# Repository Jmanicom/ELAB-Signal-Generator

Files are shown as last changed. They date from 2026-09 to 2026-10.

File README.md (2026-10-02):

# ELAB-Signal-Generator
A square wave generator with adjustable frequency, gain, and offset control. Designed as a part of UBC's ELAB PCB design course.

### **Skills used in this project**
***KiCad, Analog Circuit Design, Hand Soldering, Testing/Validation***

---

<p float="left">
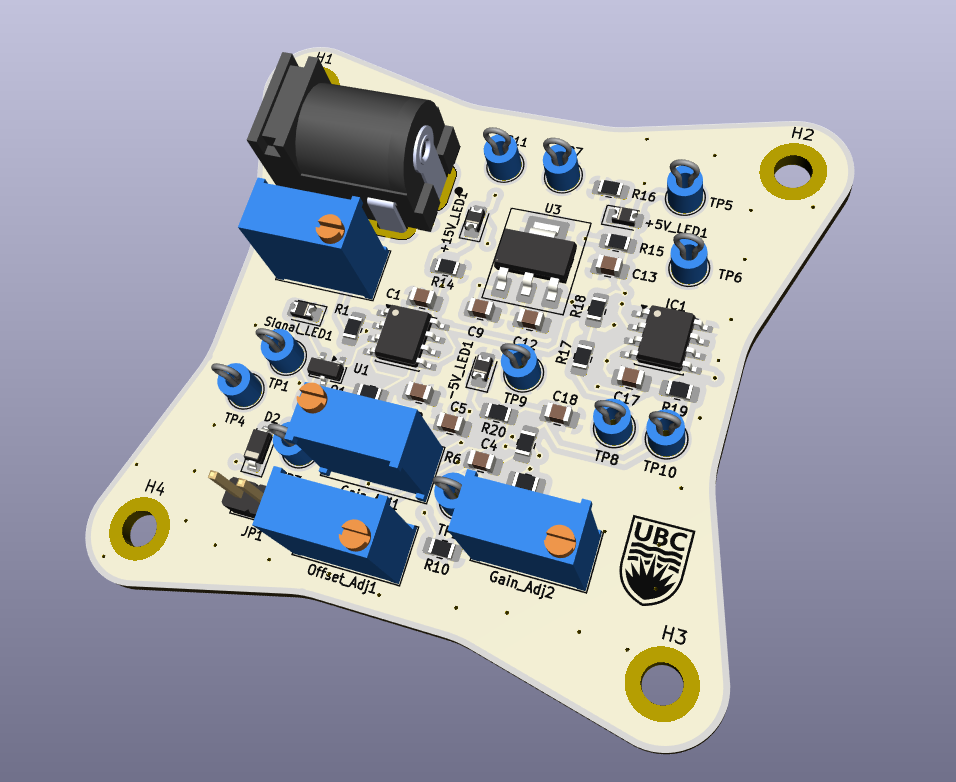
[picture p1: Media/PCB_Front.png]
  
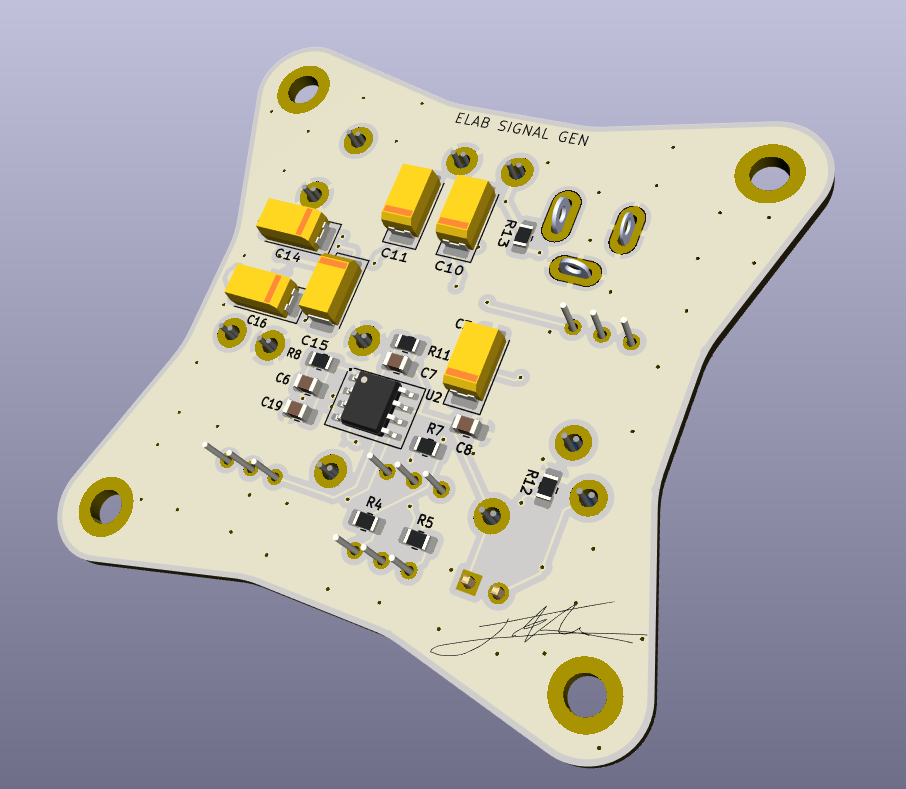
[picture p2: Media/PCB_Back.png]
  
</p>

# Design
The design for this signal generator is not complex, this is because it's main purpose was to provide an opportunity to design 
and assemble a PCB from the start to finish of the production cycle. This included schematic capture, component/footprint library 
creation, component layout, laying traces, and laying polygon pours. In the second stage of the course, we received our boards and 
components and assembled them using hand soldering, and tested them using an oscilloscope to view our signals and test the various 
adjustments.

## Power Supply
The signal generator utilizes +/-5V rails to be able produce a maximum of a 10V peak-to-peak
signal. 15V  comes from a barrel jack connections from a wall adapter, which is then 
regulated using the **LM7805** to drop to it to +5V. This rail then feeds into the **MAX889** that
produces the complimentary -5V rail. Output capacitors are used to help with input noise, and output voltage ripple.

<p>
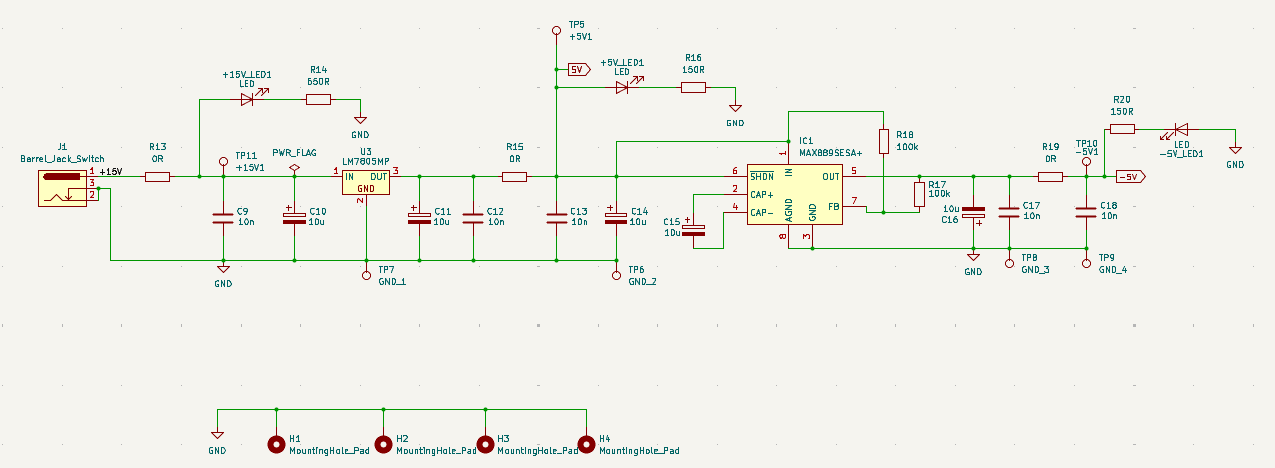
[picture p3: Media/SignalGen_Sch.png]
  
</p>

## Signal Amplifier
The square wave signal is generated by the **NE555**, that includes a frequency adjust potentiometer. This signal is then fed to 
the **AD8039** with two amplifier stages to control gain and offset respectively. Additional bypass capacitors are placed
on the op-amps power rails to help with further noise reduction and to help stabilize voltage. Finally, a 3.3V peak-limiter zener
diode is placed on the output which can be engaged with the use of a jumper. 

<p>
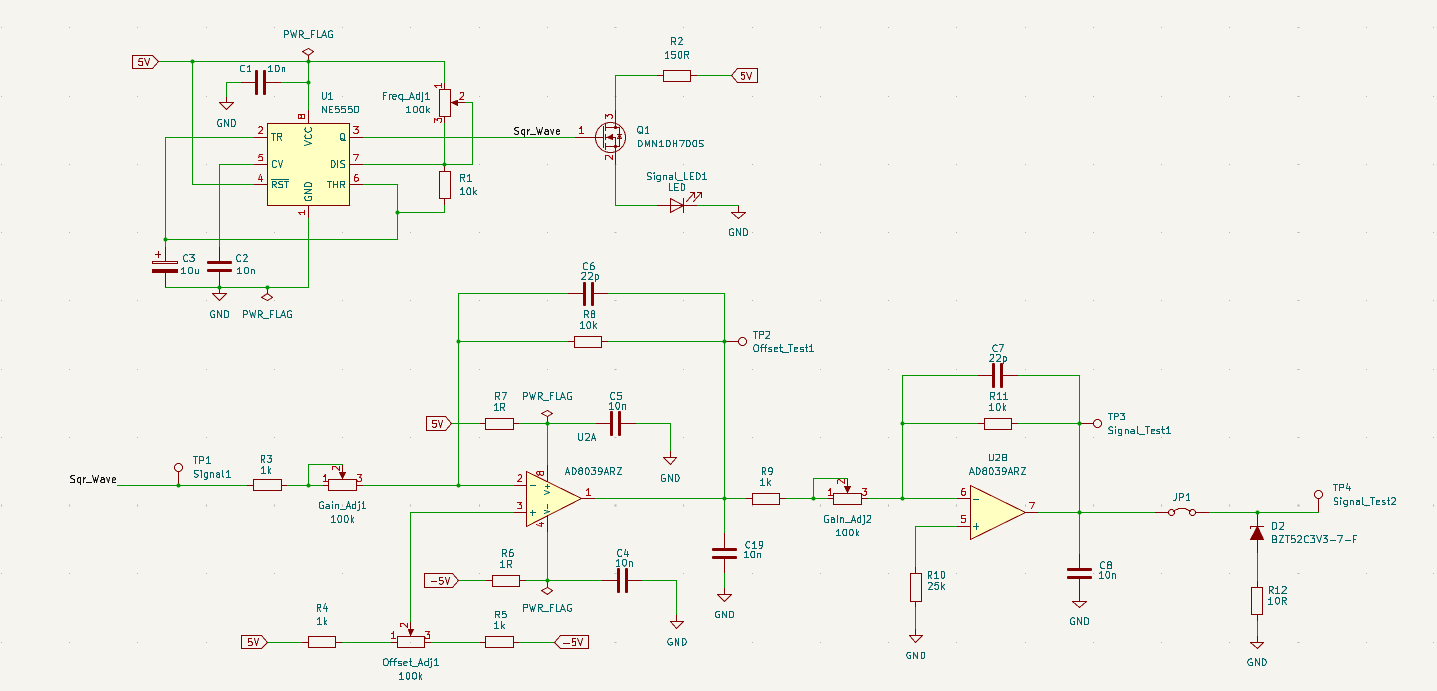
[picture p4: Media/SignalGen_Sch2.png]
  
</p>

## PCB Design
With this being my first attempt at PCB design, there is room for improvement with my traces decisions component placement.
With this project, we were constrained on the size of board that we could use, additionally, I wanted to make a unique shape
for my board that tends to be a popular shape for small desings that need to be mounted.

The large 1206 capacitors were placed on the back side of the board as they are quite bulky and left very little room for other
components on the board. This board features 2-layers with ground pours on each layer, as well as stitching vias to help further
with noise.

<p float="left">
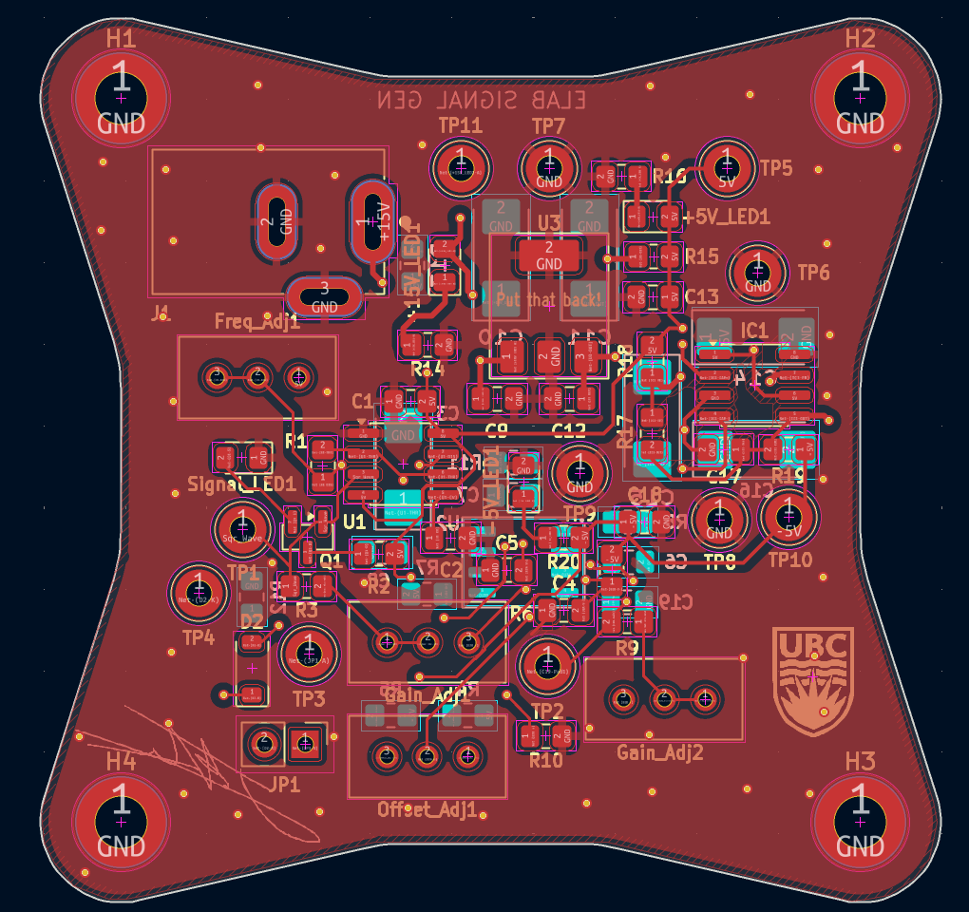
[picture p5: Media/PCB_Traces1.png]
  
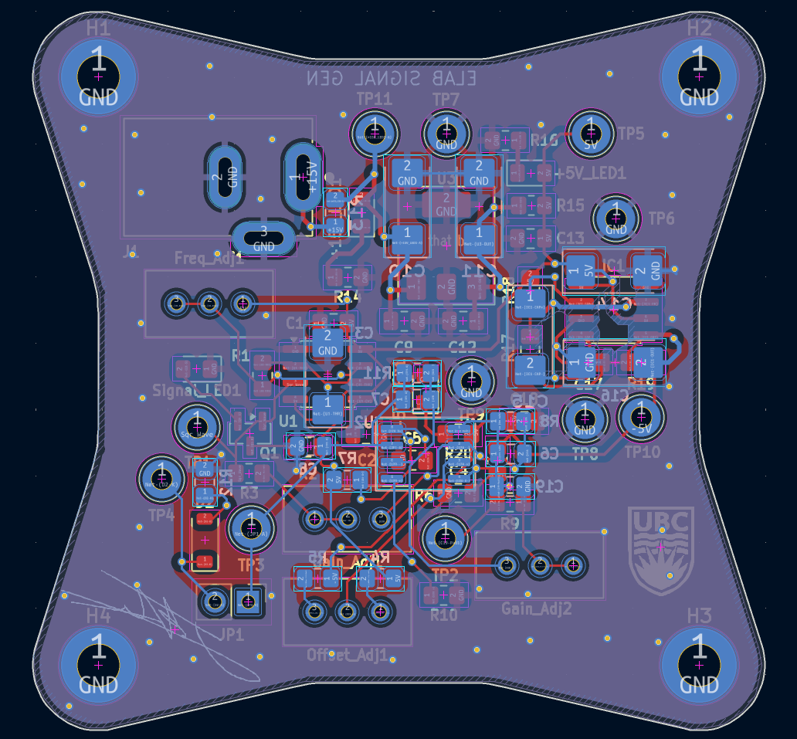
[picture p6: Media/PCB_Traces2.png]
  
</p>

# Assembly

# Testing

# Notes

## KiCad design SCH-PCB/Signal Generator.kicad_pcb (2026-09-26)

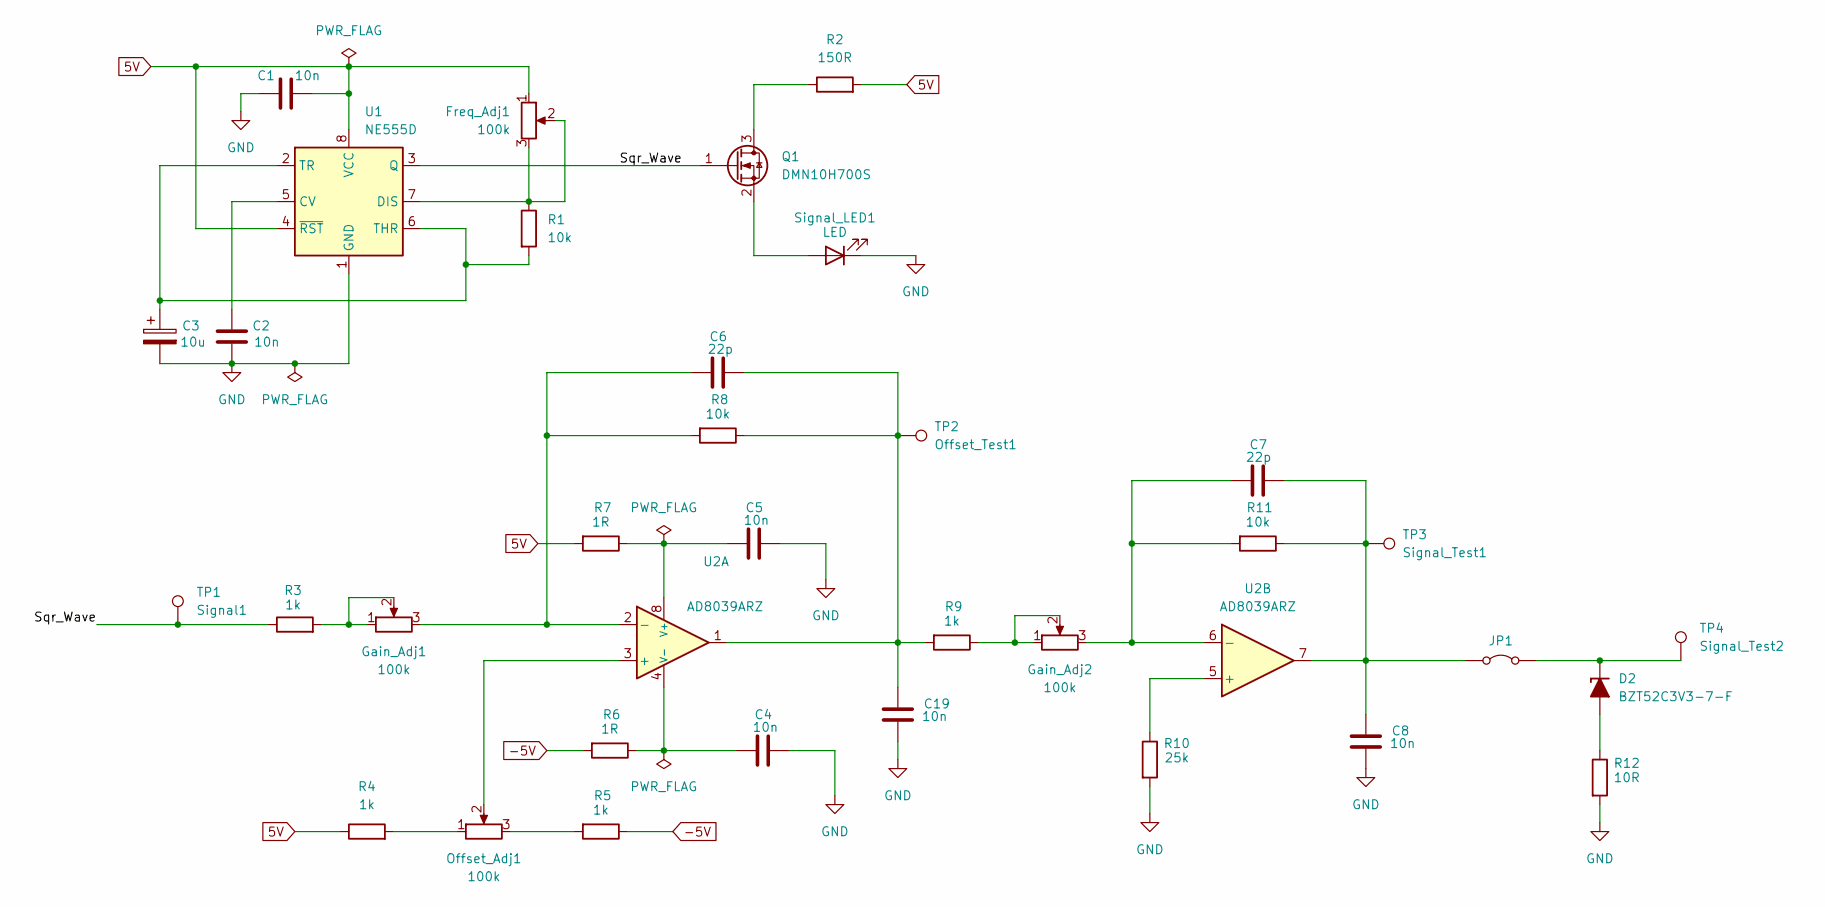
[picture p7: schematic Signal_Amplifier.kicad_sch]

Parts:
C1, C2, C4, C5, C8, C19: 10n; C_0805_2012Metric_Pad1.18x1.45mm_HandSolder
C3: 10u; CP_EIA-6032-28_Kemet-C_HandSolder
C6, C7: 22p; C_0805_2012Metric_Pad1.18x1.45mm_HandSolder
D2: BZT52C3V3-7-F; D_SOD-123
Freq_Adj1: 100k; Potentiometer_Bourns_3296W_Vertical
Gain_Adj1, Gain_Adj2: 100k; Potentiometer_Bourns_3296W_Vertical
JP1: Jumper_2_Bridged; PinHeader_1x02_P2.54mm_Vertical
Offset_Adj1: 100k; Potentiometer_Bourns_3296W_Vertical
Q1: DMN10H700S; SOT-23
R1, R8, R11: 10k; R_0805_2012Metric_Pad1.20x1.40mm_HandSolder
R2: 150R; R_0805_2012Metric_Pad1.20x1.40mm_HandSolder
R3, R4, R5, R9: 1k; R_0805_2012Metric_Pad1.20x1.40mm_HandSolder
R6, R7: 1R; R_0805_2012Metric_Pad1.20x1.40mm_HandSolder
R10: 25k; R_0805_2012Metric_Pad1.20x1.40mm_HandSolder
R12: 10R; R_0805_2012Metric_Pad1.20x1.40mm_HandSolder
Signal_LED1: LED; D_0805_2012Metric_Pad1.15x1.40mm_HandSolder
TP1: Signal1; TestPoint_Loop_D2.54mm_Drill1.5mm_Beaded
TP2: Offset_Test1; TestPoint_Loop_D2.54mm_Drill1.5mm_Beaded
TP3: Signal_Test1; TestPoint_Loop_D2.54mm_Drill1.5mm_Beaded
TP4: Signal_Test2; TestPoint_Loop_D2.54mm_Drill1.5mm_Beaded
U1: NE555D; SOIC-8_3.9x4.9mm_P1.27mm
U2: AD8039ARZ; SO-8_3.9x4.9mm_P1.27mm

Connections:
5V: C1.2, Freq_Adj1.1, R2.2, R4.1, R7.2, U1.4 (~RST), U1.8 (VCC); also elsewhere on the board
-5V: R5.1, R6.2; also elsewhere on the board
/Signal_Amplifier/Sqr_Wave: Q1.1 (G), R3.1, TP1.1 (1_1), U1.3 (Q)
GND: C1.1, C2.2, C3.2, C4.1, C5.1, C8.2, C19.2, R10.2, R12.2, Signal_LED1.1 (K), U1.1 (GND); also elsewhere on the board
unnamed: C6.1, C19.1, R8.1, R9.2, TP2.1 (1_1), U2.1
unnamed: D2.2 (A), R12.1
unnamed: D2.1 (K), JP1.2 (B), TP4.1 (1_1)
unnamed: Gain_Adj1.1, Gain_Adj1.2, R3.2
unnamed: Gain_Adj2.1, Gain_Adj2.2, R9.1
unnamed: C7.1, C8.1, JP1.1 (A), R11.1, TP3.1 (1_1), U2.7
unnamed: Offset_Adj1.1, R4.2
unnamed: Offset_Adj1.3, R5.2
unnamed: Q1.3 (D), R2.1
unnamed: Q1.2 (S), Signal_LED1.2 (A)
unnamed: C2.1, U1.5 (CV)
unnamed: Freq_Adj1.2, Freq_Adj1.3, R1.1, U1.7 (DIS)
unnamed: C3.1, R1.2, U1.2 (TR), U1.6 (THR)
unnamed: Offset_Adj1.2, U2.3 (+)
unnamed: C6.2, Gain_Adj1.3, R8.2, U2.2 (-)
unnamed: C5.2, R7.1, U2.8 (V+)
unnamed: C4.2, R6.1, U2.4 (V-)
unnamed: R10.1, U2.5 (+)
unnamed: C7.2, Gain_Adj2.3, R11.2, U2.6 (-)

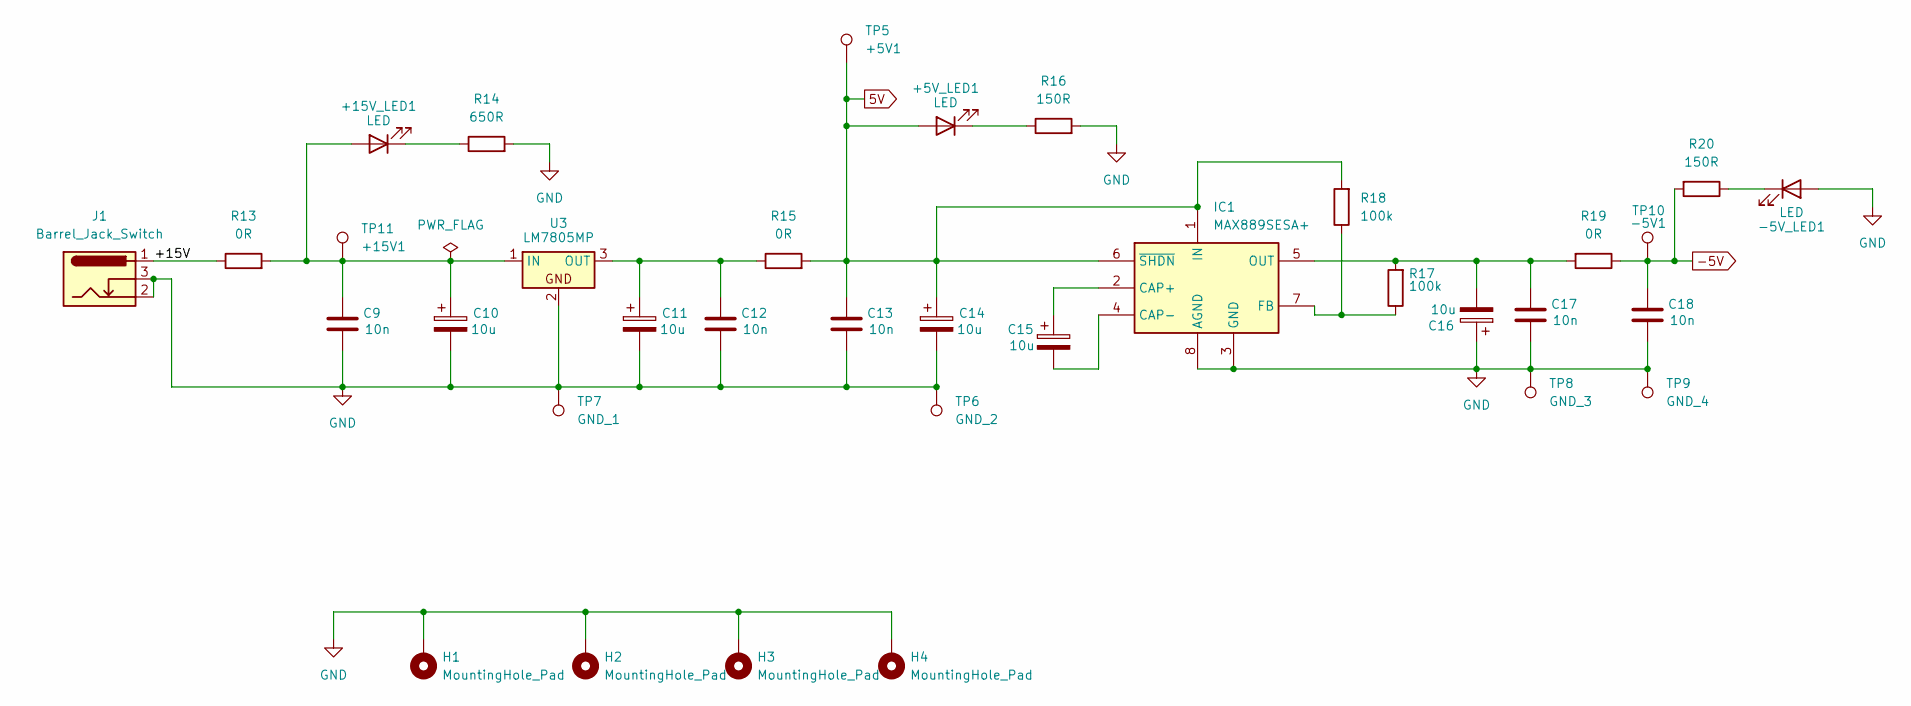
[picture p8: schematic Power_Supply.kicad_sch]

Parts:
+5V_LED1, +15V_LED1: LED; D_0805_2012Metric_Pad1.15x1.40mm_HandSolder
-5V_LED1: LED; D_0805_2012Metric_Pad1.15x1.40mm_HandSolder
C9, C12, C13, C17, C18: 10n; C_0805_2012Metric_Pad1.18x1.45mm_HandSolder
C10, C11, C14, C15, C16: 10u; CP_EIA-6032-28_Kemet-C_HandSolder
H1, H2, H3, H4: MountingHole_Pad; MountingHole_3.2mm_M3_DIN965_Pad
IC1: MAX889SESA+; SOIC-8_3.9x4.9mm_P1.27mm; Manufacturer_Part_Number MAX889SESA+; Mouser Part Number 700-MAX889SESA
J1: Barrel_Jack_Switch; CUI_PJ-002A
R13, R15, R19: 0R; R_0805_2012Metric_Pad1.20x1.40mm_HandSolder
R14: 650R; R_0805_2012Metric_Pad1.20x1.40mm_HandSolder
R16, R20: 150R; R_0805_2012Metric_Pad1.20x1.40mm_HandSolder
R17, R18: 100k; R_0805_2012Metric_Pad1.20x1.40mm_HandSolder
TP5: +5V1; TestPoint_Loop_D2.54mm_Drill1.5mm_Beaded
TP6: GND_2; TestPoint_Loop_D2.54mm_Drill1.5mm_Beaded
TP7: GND_1; TestPoint_Loop_D2.54mm_Drill1.5mm_Beaded
TP8: GND_3; TestPoint_Loop_D2.54mm_Drill1.5mm_Beaded
TP9: GND_4; TestPoint_Loop_D2.54mm_Drill1.5mm_Beaded
TP10: -5V1; TestPoint_Loop_D2.54mm_Drill1.5mm_Beaded
TP11: +15V1; TestPoint_Loop_D2.54mm_Drill1.5mm_Beaded
U3: LM7805MP; SOT-223-3_TabPin2

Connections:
5V: +5V_LED1.2 (A), C13.1, C14.1, IC1.1 (IN), IC1.6 (~SHDN), R15.2, R18.2, TP5.1 (1_1); also elsewhere on the board
-5V: C18.1, R19.1, R20.2, TP10.1 (1_1); also elsewhere on the board
/Power_Supply/+15V: J1.1, R13.1
GND: -5V_LED1.2 (A), C9.2, C10.2, C11.2, C12.2, C13.2, C14.2, C16.1, C17.2, C18.2, H1.1 (1_1), H2.1 (1_1), H3.1 (1_1), H4.1 (1_1), IC1.3 (GND), IC1.8 (AGND), J1.2, J1.3, R14.2, R16.2, TP6.1 (1_1), TP7.1 (1_1), TP8.1 (1_1), TP9.1 (1_1), U3.2; also elsewhere on the board
unnamed: +5V_LED1.1 (K), R16.1
unnamed: +15V_LED1.2 (A), C9.1, C10.1, R13.2, TP11.1 (1_1), U3.1 (IN)
unnamed: +15V_LED1.1 (K), R14.1
unnamed: -5V_LED1.1 (K), R20.1
unnamed: C15.1, IC1.2 (CAP+)
unnamed: C15.2, IC1.4 (CAP-)
unnamed: IC1.7 (FB), R17.1, R18.1
unnamed: C16.2, C17.1, IC1.5 (OUT), R17.2, R19.2
unnamed: C11.1, C12.1, R15.1, U3.3 (OUT)

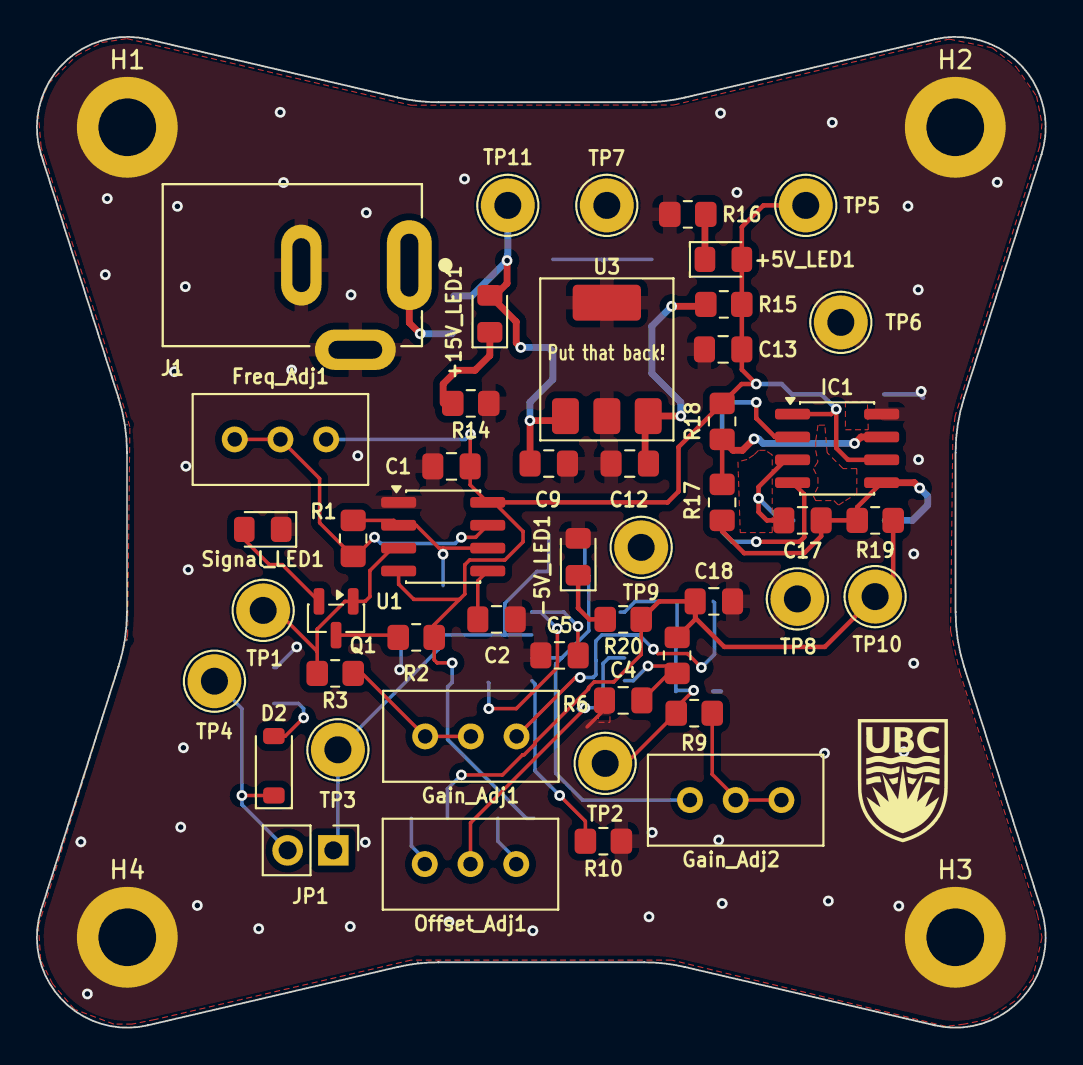
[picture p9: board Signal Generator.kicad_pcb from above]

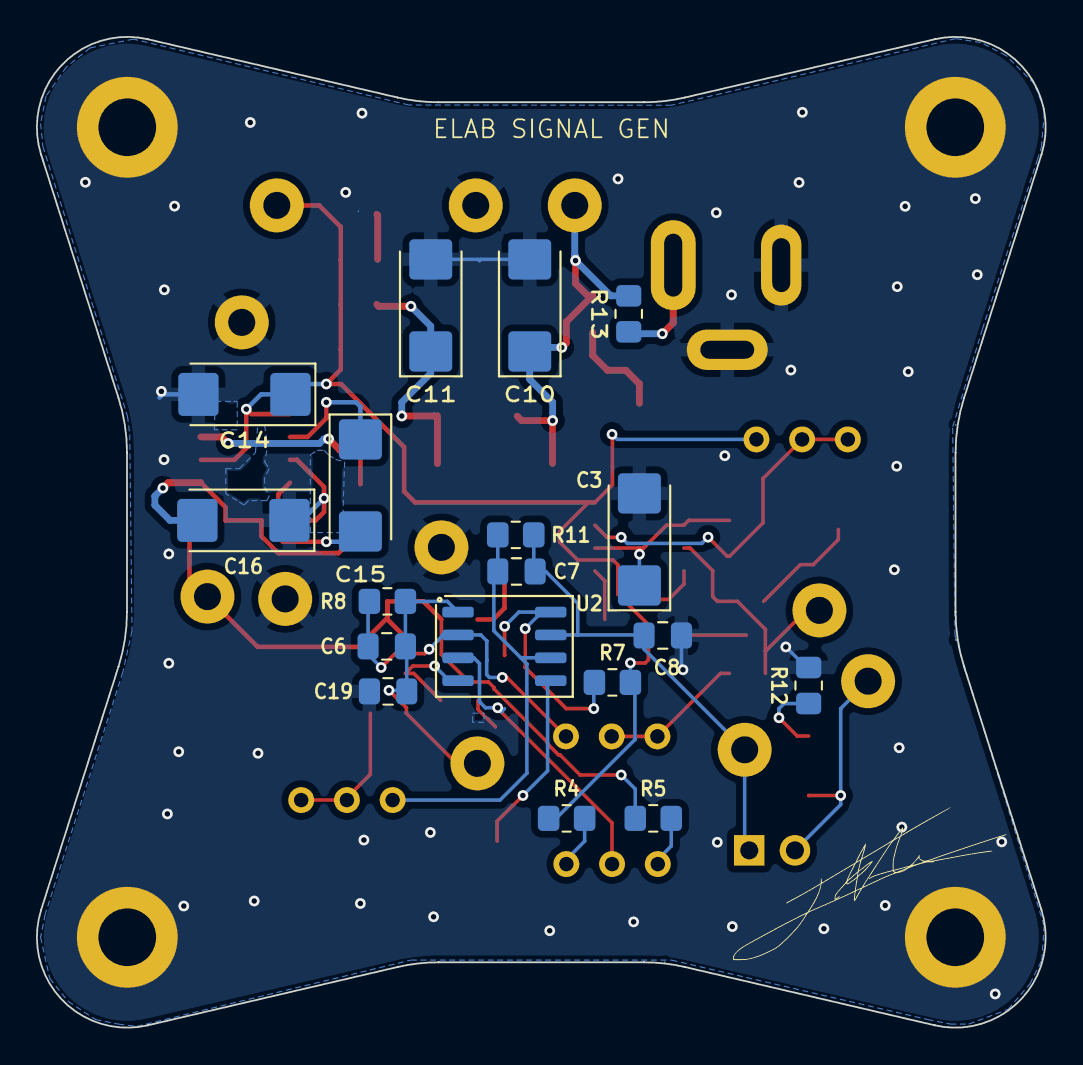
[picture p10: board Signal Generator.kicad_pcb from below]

Board: 2 copper layers, 56.0 x 55.0 mm, 70 parts (18 on the bottom side), 33 nets.

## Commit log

2026-09-26 Uploaded media and project files
    [Power_Supply.kicad_sch, Signal Generator.kicad_pcb, Signal Generator.kicad_sch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]
2026-09-26 Add height attribute to PCB images in README
    Updated image tags in README to include height attribute.
2026-09-26 Adjust height of PCB_Back image in README
    Updated the height of the PCB_Back image in the README.
2026-09-26 Adjust PCB_Back image height in README
    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
2026-09-26 Fix height of PCB_Back image in README
    Adjusted the height of the PCB_Back image in the README.
2026-09-26 Update PCB_Front image in README
    Remove height attribute from PCB_Front image.
2026-09-29 Adjust PCB_Back image height in README
    Updated the height of the PCB_Back image in README.
2026-09-29 Fix PCB_Back image height in README
    Adjusted the height of the PCB_Back image for better layout.
2026-10-01 Added PCB trace design
2026-10-01 Correct image tag for PCB_Traces2 in README
    Fix HTML tag formatting for PCB_Traces2 image.
